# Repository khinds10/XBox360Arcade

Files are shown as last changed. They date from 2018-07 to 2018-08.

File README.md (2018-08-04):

# XBox360 Arcade - using a computer monitor speaker parts and 2 fightstick game pads, make an exciting arcade for your own home

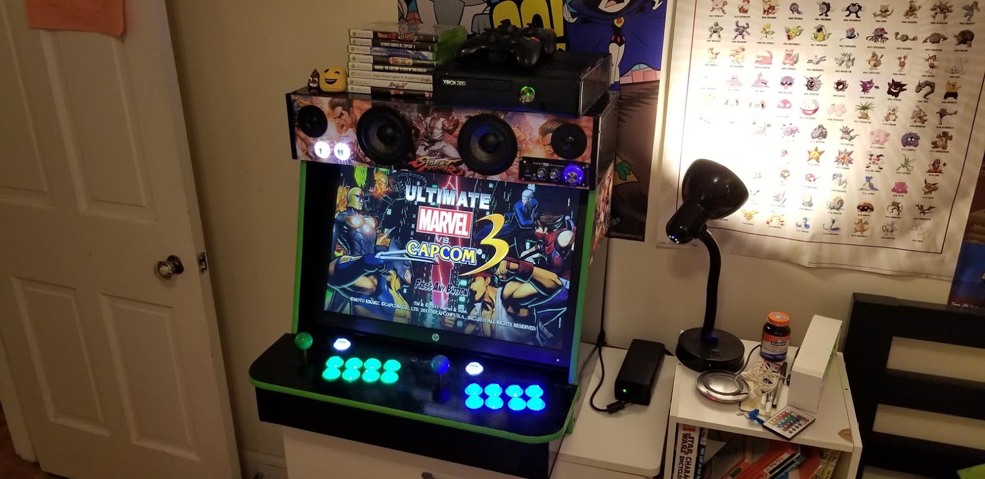
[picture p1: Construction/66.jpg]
Complete


## Supplied needed

### Construction Materials

#### Black Gloss Paint

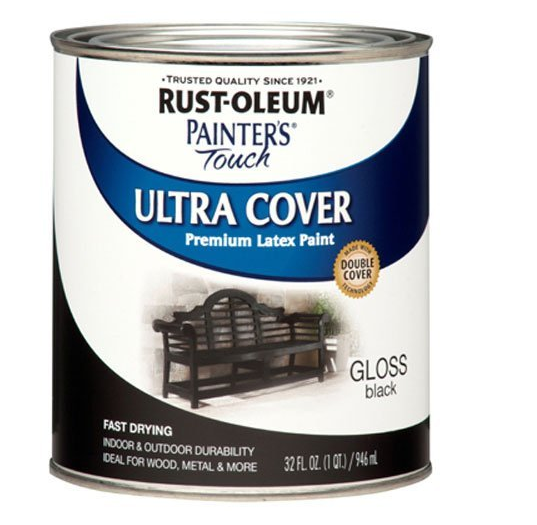
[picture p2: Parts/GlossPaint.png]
Black Gloss Paint


#### 1 inch Hole Saw

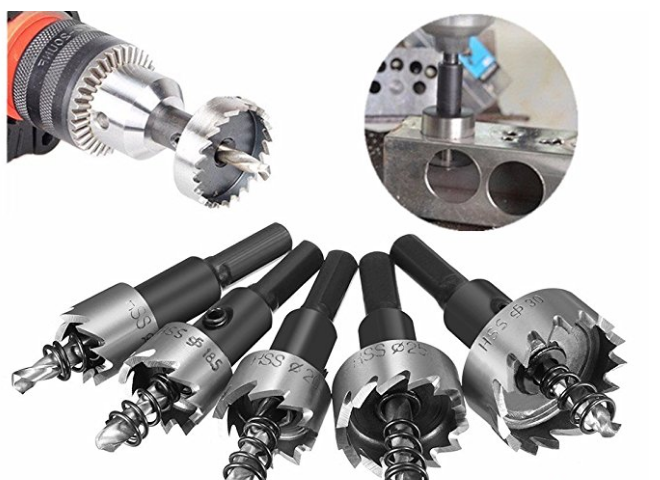
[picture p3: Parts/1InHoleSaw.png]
1 inch Hole Saw


#### Clear Gloss Coat

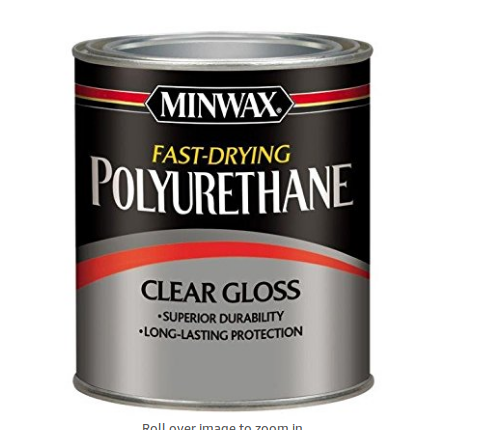
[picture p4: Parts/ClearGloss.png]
Clear Gloss Coat


#### 1x4 Wood Planks

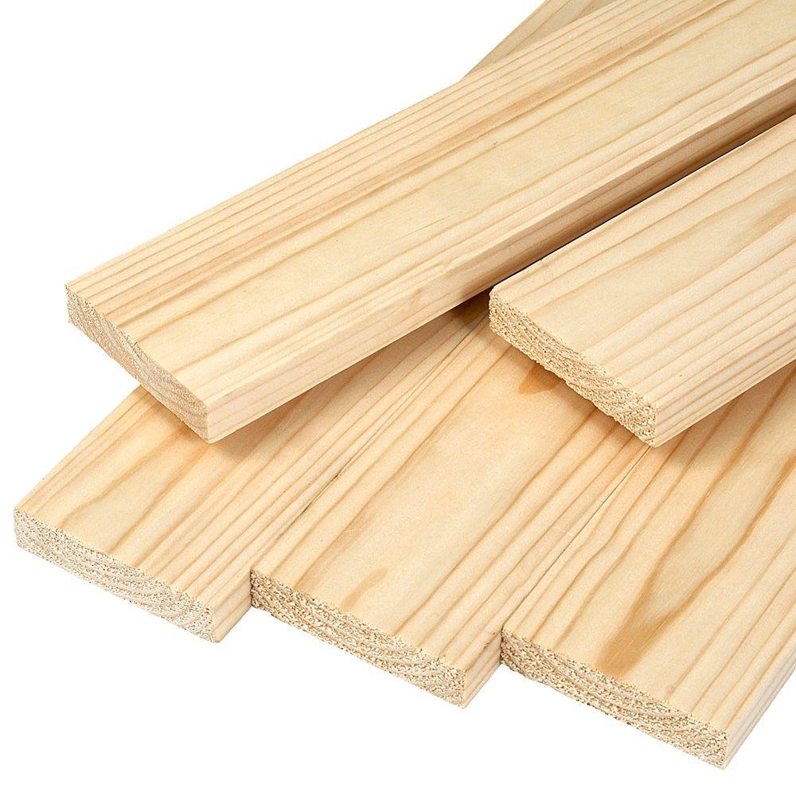
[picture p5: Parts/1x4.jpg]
1x4 Wood


#### Particle Board

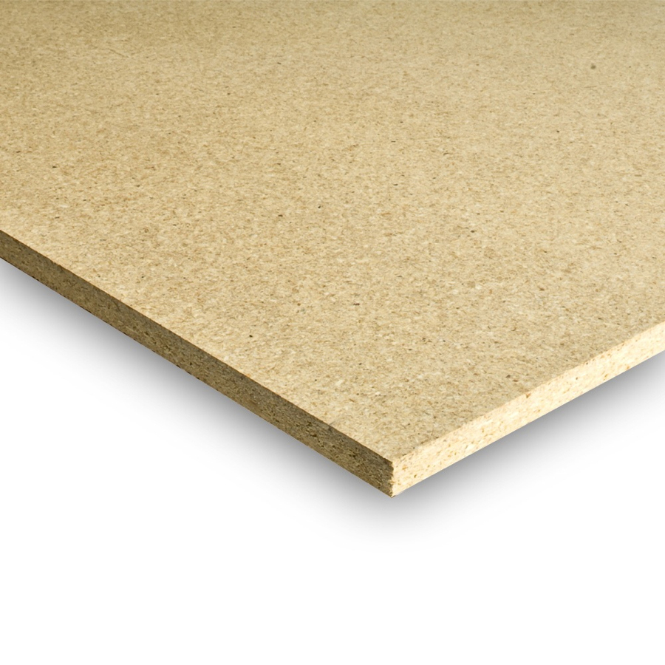
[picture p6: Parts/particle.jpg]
Particle Board


### Electronics

#### 24 inch Monitor

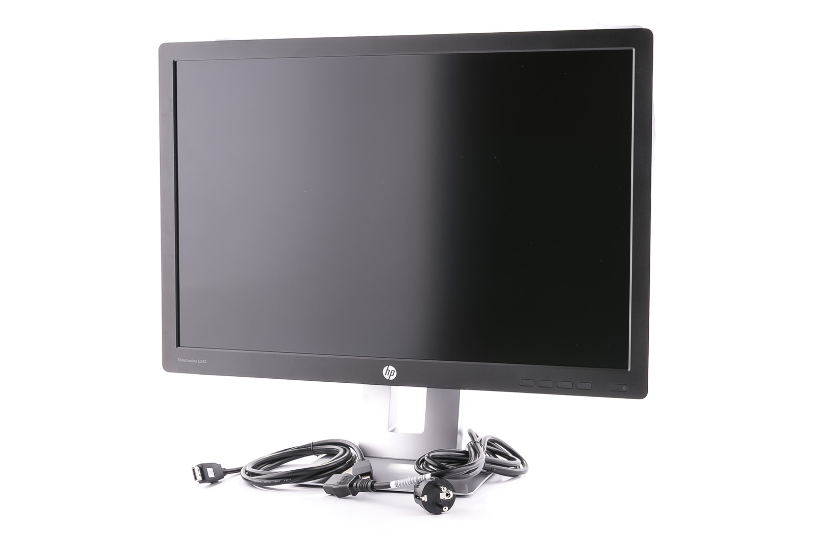
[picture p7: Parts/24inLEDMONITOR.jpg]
24 inch Monitor


#### Mini 12v Amplifier

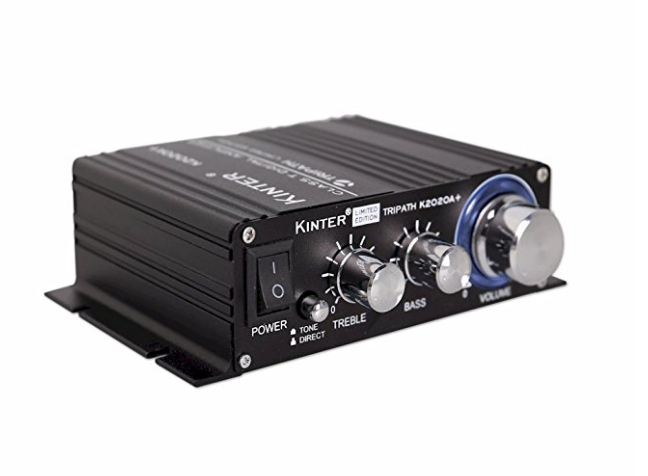
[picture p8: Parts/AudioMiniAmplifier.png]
Mini 12v Amplifier


#### XBox 360

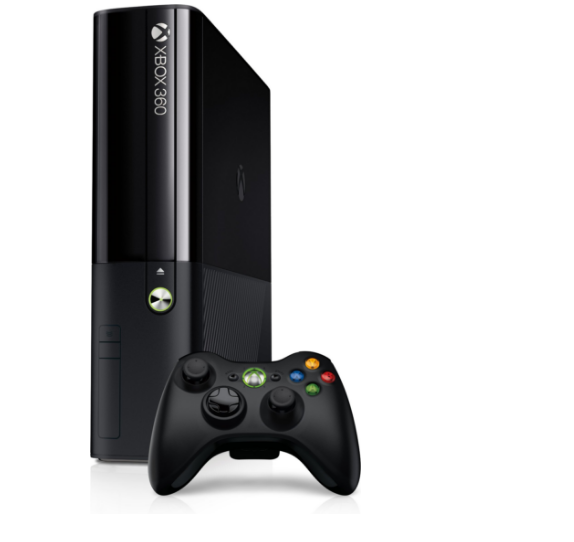
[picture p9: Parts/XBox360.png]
XBox 360


#### Fightstick (x2)

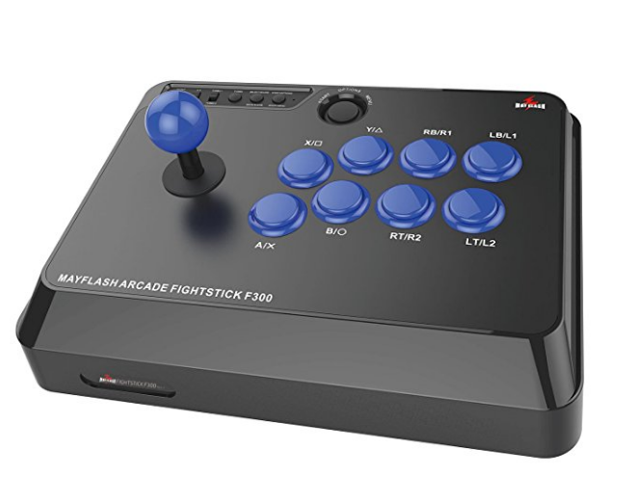
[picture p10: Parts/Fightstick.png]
Fightstick


#### XBox360 Controller (x2)

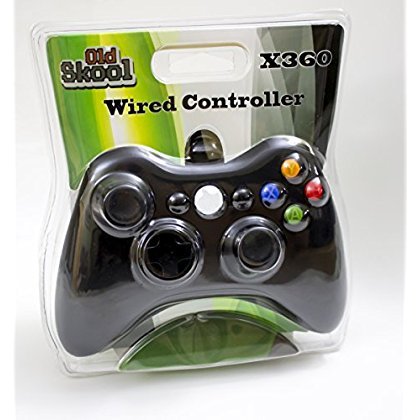
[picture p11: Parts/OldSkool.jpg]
XBox360 Controller (x2)


#### Power Strip

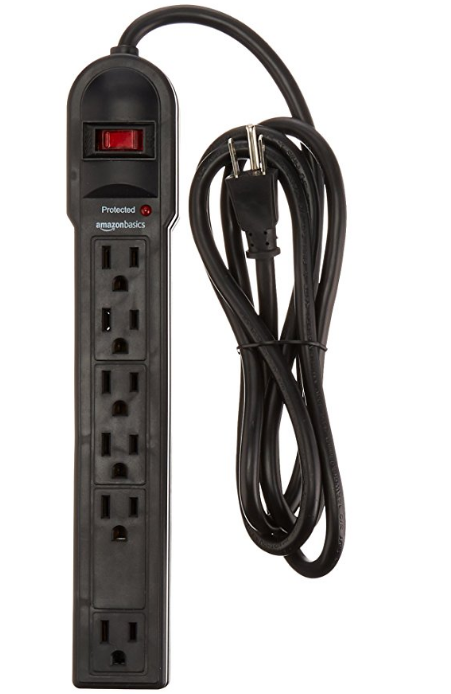
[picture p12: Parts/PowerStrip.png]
Power Strip


#### RCA Cables

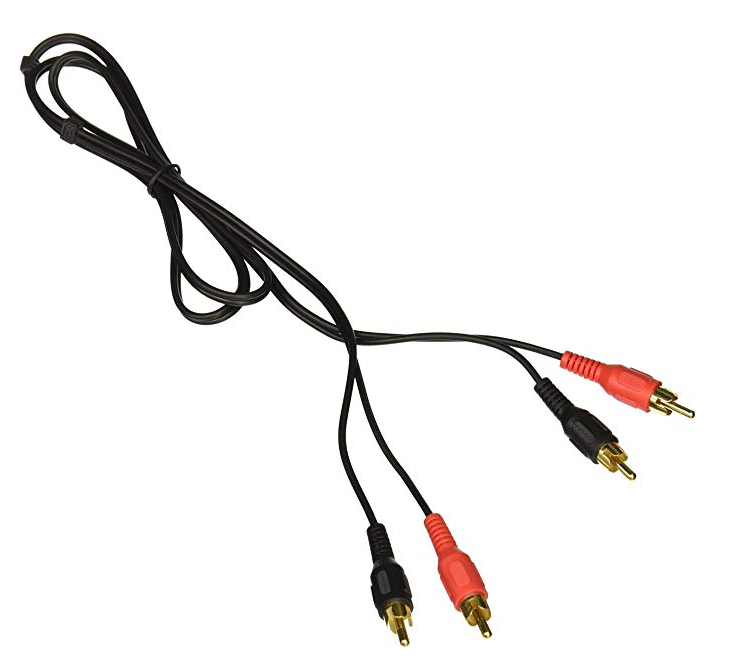
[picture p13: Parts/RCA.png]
RCA Cables


#### Small Speakers

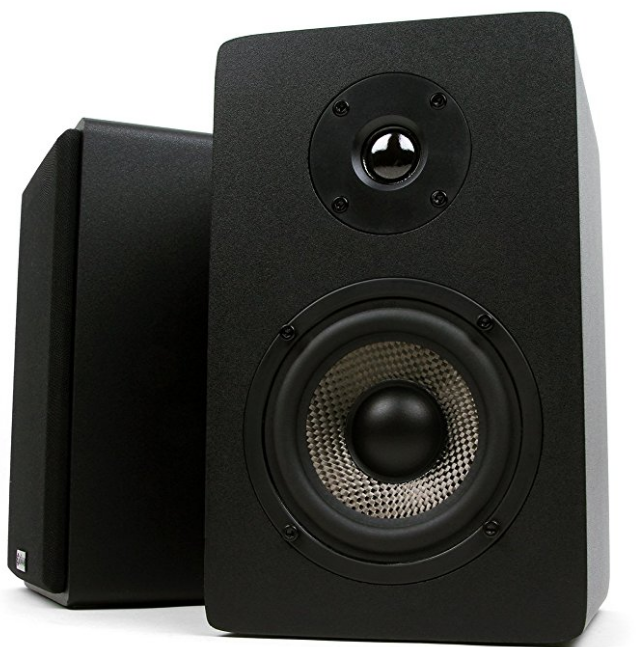
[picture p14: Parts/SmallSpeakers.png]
Small Speakers


#### HDMI Audio Extractor

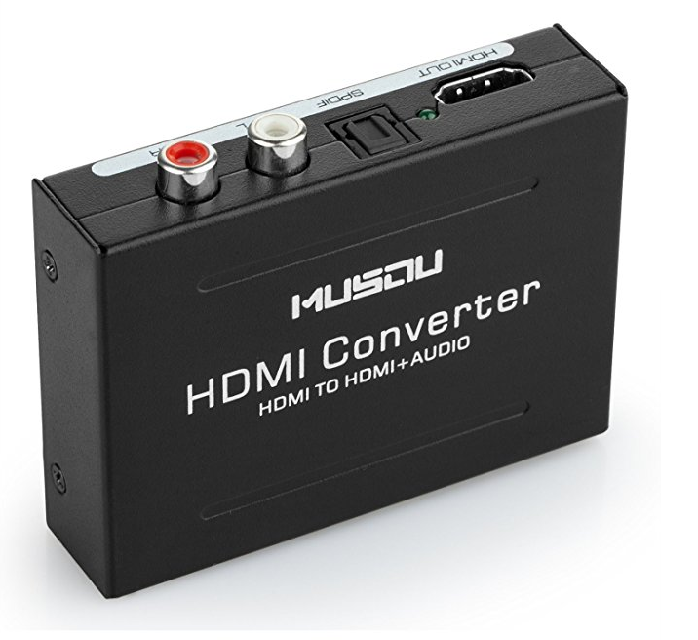
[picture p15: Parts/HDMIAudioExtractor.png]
HDMI Audio Extractor


#### Illuminated Buttons

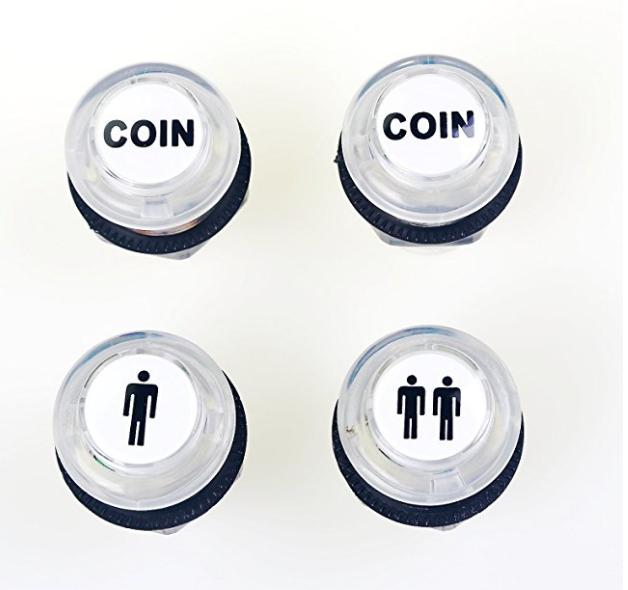
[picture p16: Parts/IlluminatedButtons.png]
Illuminated Buttons


#### Illuminated Buttons Kit

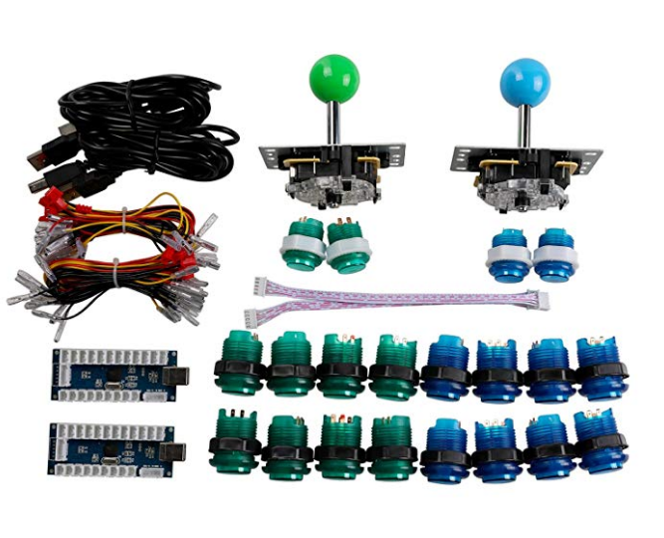
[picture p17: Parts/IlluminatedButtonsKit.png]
Illuminated Buttons Kit


#### Green TMolding

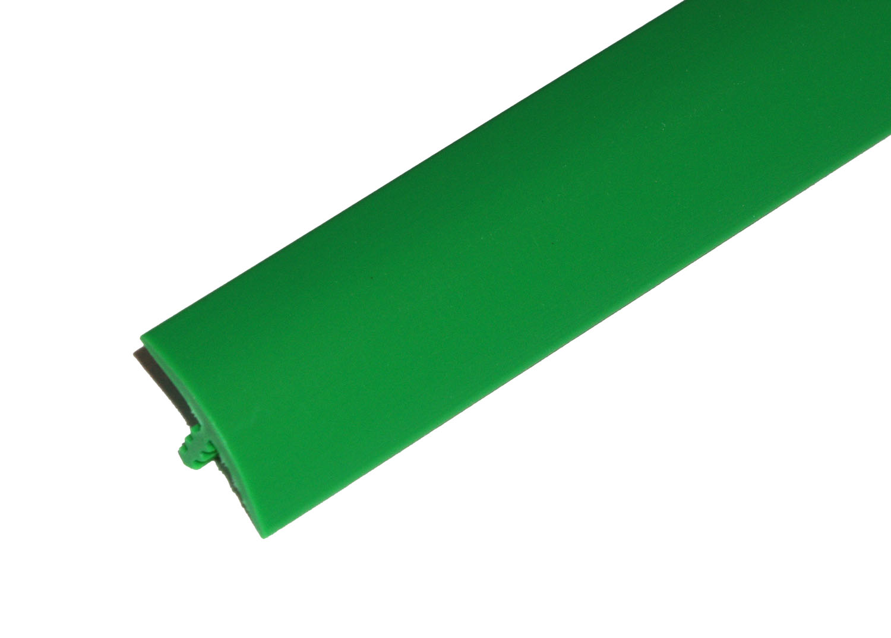
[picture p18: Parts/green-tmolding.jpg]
Green TMolding


### Exterior Decals

#### Decals

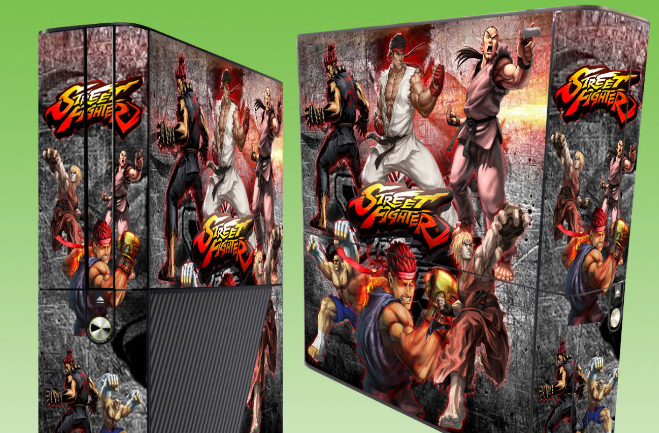
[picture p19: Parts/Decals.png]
Decals


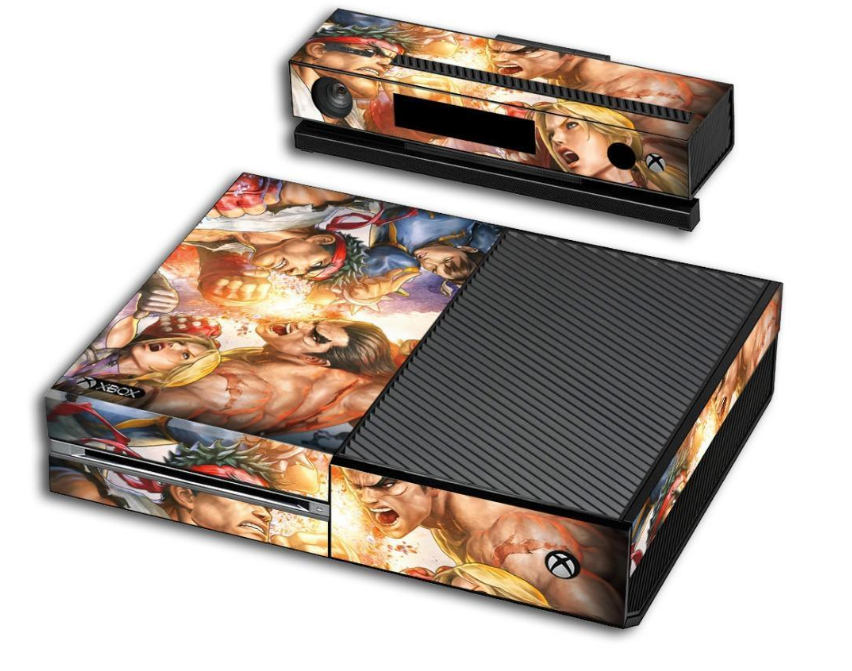
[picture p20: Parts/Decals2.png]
Decals


#### Embossed Branding Stickers

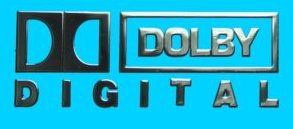
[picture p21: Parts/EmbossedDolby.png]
Dolby Sticker


XBox Sticker

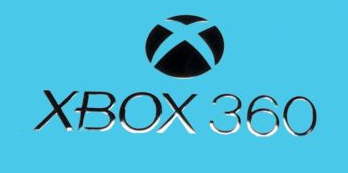
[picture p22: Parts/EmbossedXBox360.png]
XBox Sticker


## Building the Arcade

Because the Fightstick joysticks need an actual XBox360 controller plugged in to work and the "home" button has to be physically pressed on the joystick before the fightstick connects correctly, the following is needed to get the "home" or "player 1 / player 2" buttons to work on the arcade.

Take 2 XBox360 controllers and disassemble them.  Where the buttons would normally "press" (the circular metal contact connection), use a light sandpaper to expose the metal.

Soldered a "home" button connection directly to the contacts of where the home button would normally press if it was still put together.  This lets the joystick button "press" home as if it were a rubber button inside the original controller.

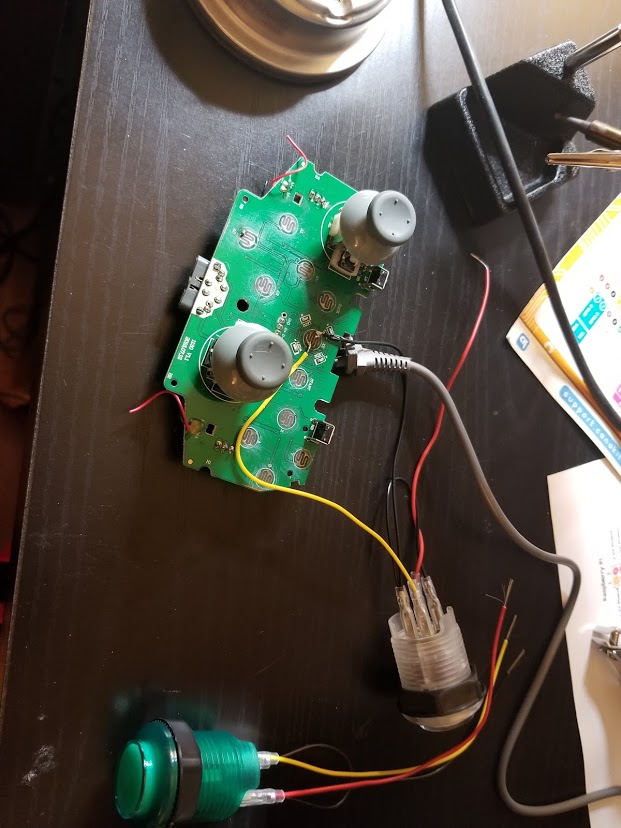
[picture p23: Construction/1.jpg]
Install Home Button


##### Build a basic Frame from the 1x4 planks to hold the monitor in place in the shape of an arcade cabinet

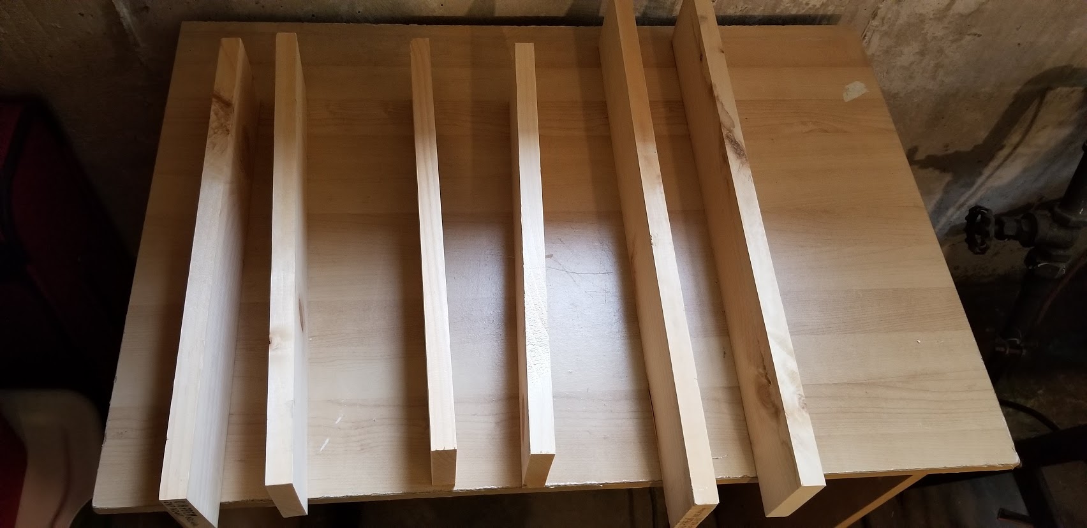
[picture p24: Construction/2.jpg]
Gather Wood

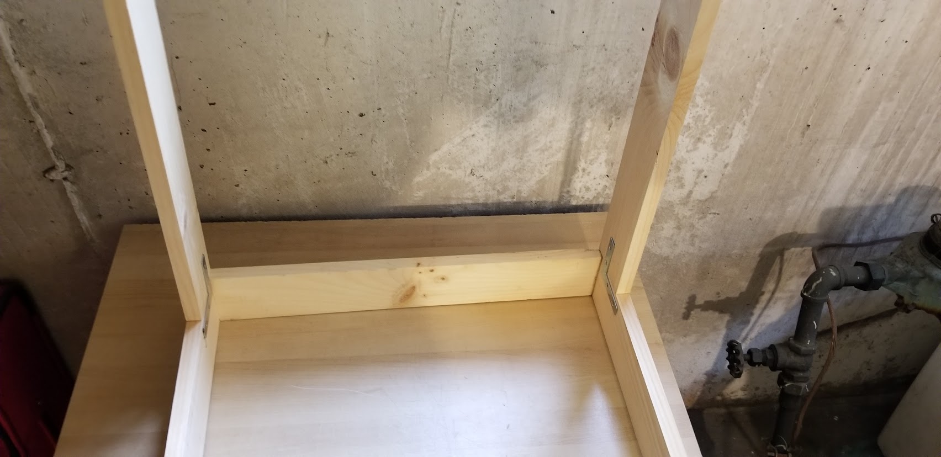
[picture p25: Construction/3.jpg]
Build Frame cont... Build Frame

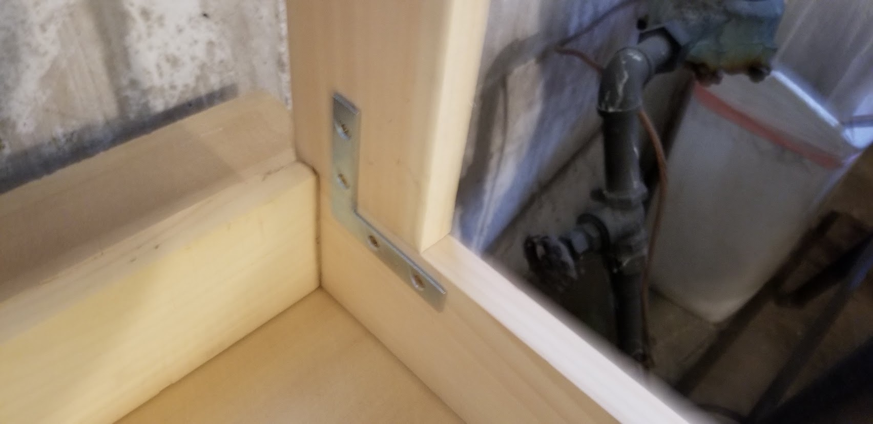
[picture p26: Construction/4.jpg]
Build Frame cont... Build Frame cont.

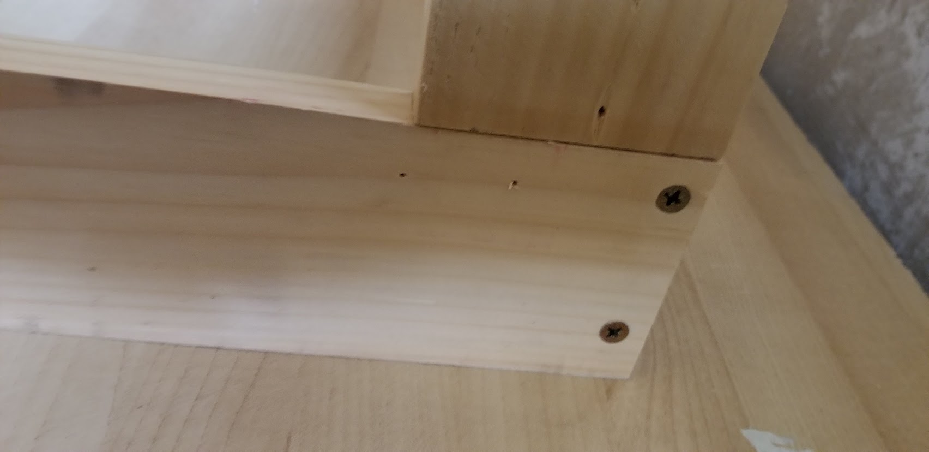
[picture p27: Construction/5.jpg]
Build Frame cont...


##### Make sure the monitor fits correctly across the build

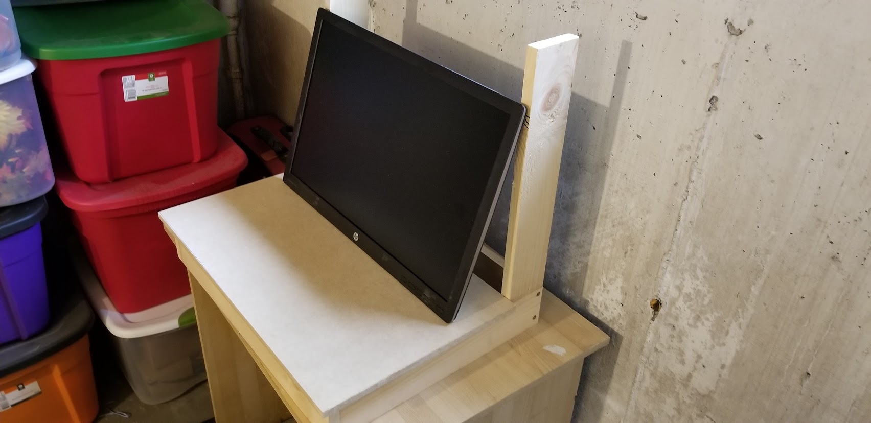
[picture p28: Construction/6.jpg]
Measure Monitor to fit

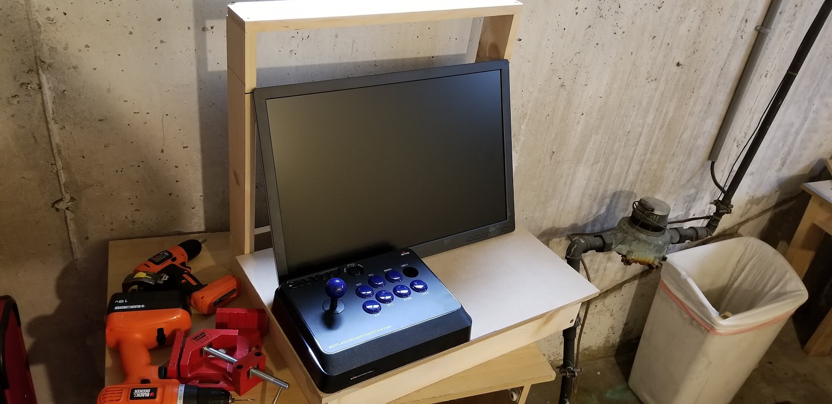
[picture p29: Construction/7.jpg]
Measure Monitor to fit cont...


##### Using the table saw, don't cut all the way through, but leave a slit in the wood where the bottom edge of the monitor would go, this will allow to place a thin piece of balsa wood to fit along it to keep the monitor from sliding out forward

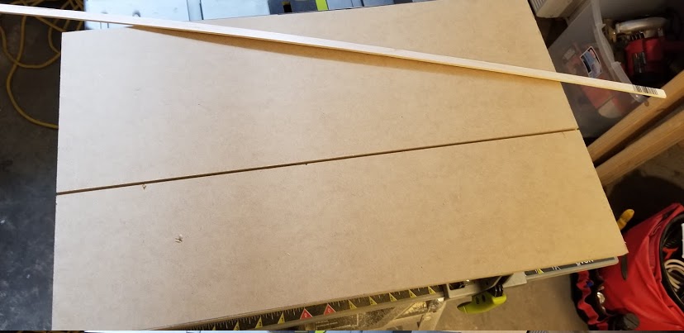
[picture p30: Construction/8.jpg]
Recess to hold monitor

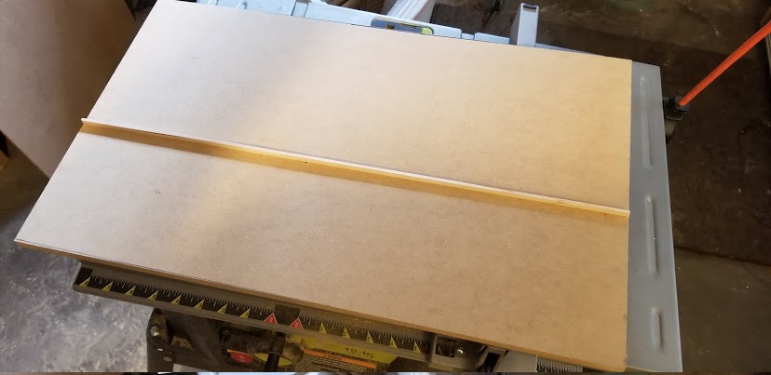
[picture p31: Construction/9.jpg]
Recess to hold monitor cont...


##### Using the fightstick button holes as a guide, drill using the 1" hole cutter the holes for where the buttons will go

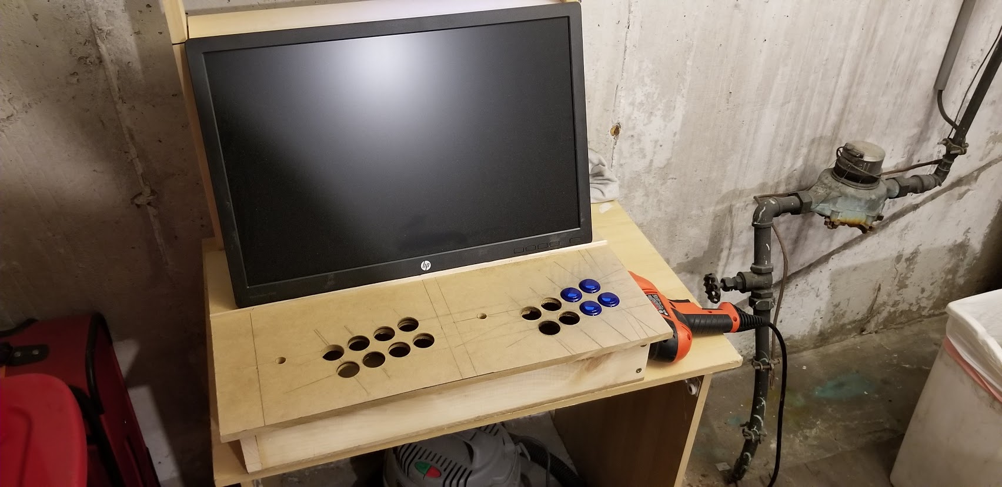
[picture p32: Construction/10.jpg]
Drill Button Holes

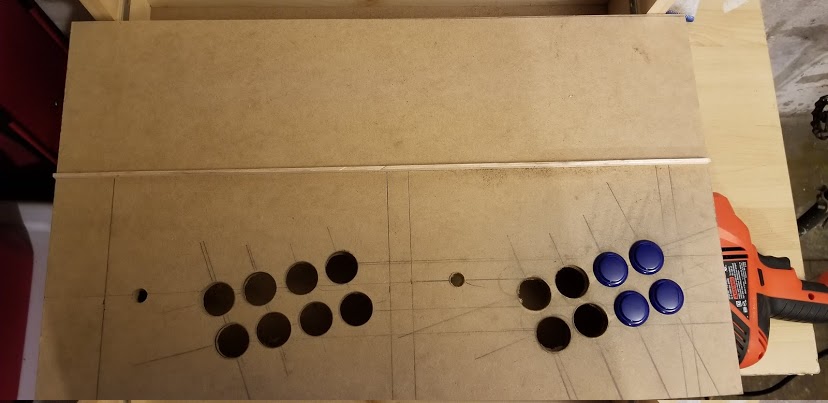
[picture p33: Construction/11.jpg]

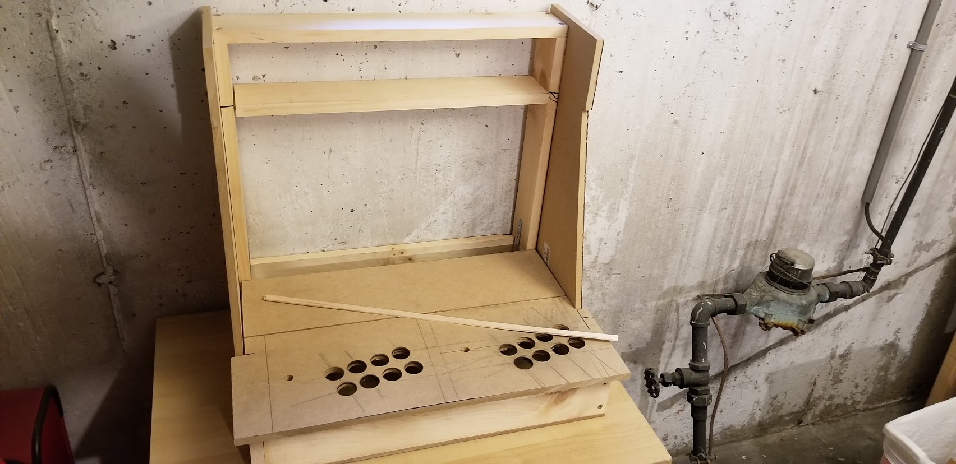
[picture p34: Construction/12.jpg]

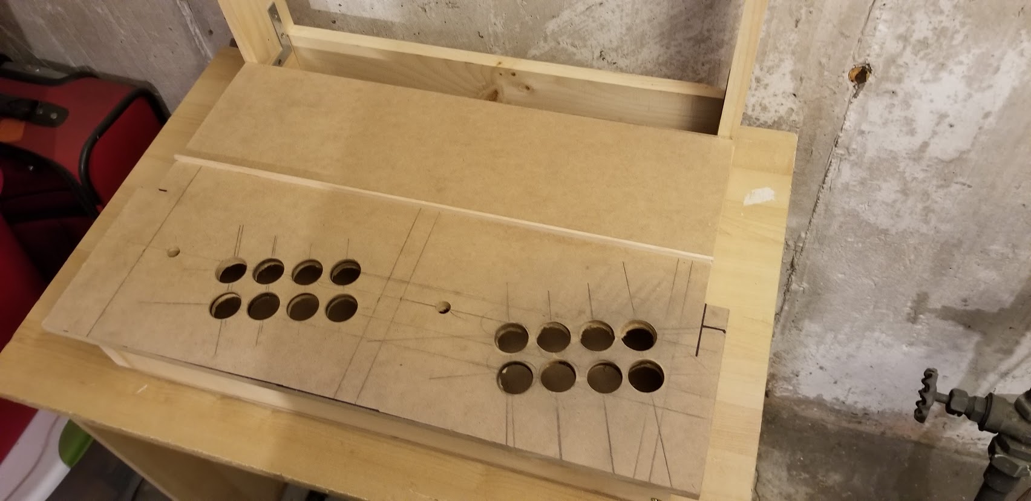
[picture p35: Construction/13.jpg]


##### With the particle board, cut the side panels with a triangular slant, however leaving the top in a square shape to contain the "top bar" where the amp / speakers will go

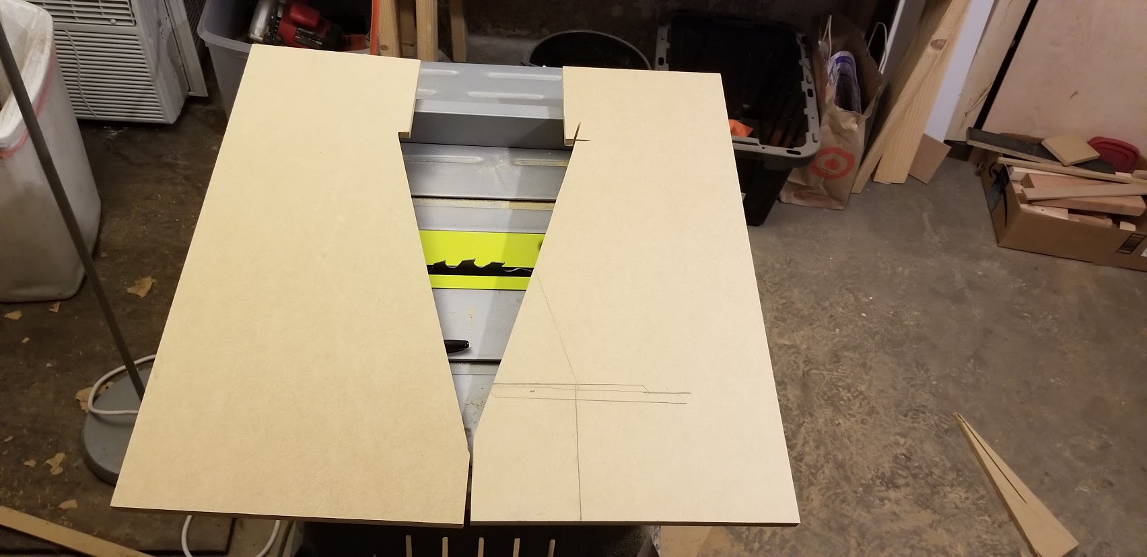
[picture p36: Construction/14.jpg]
Cut side panels from Particle Board

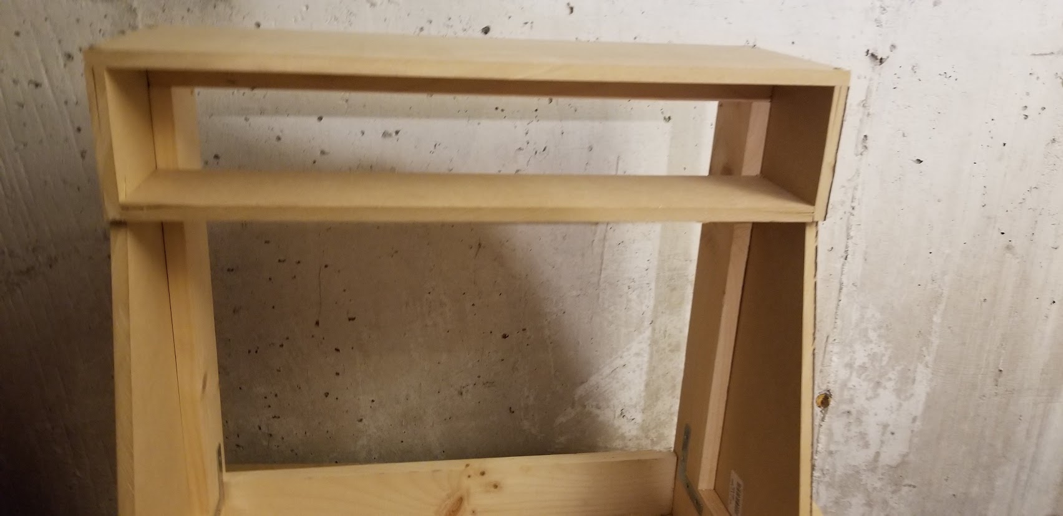
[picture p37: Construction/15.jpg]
Assemble top from 1x4 planks

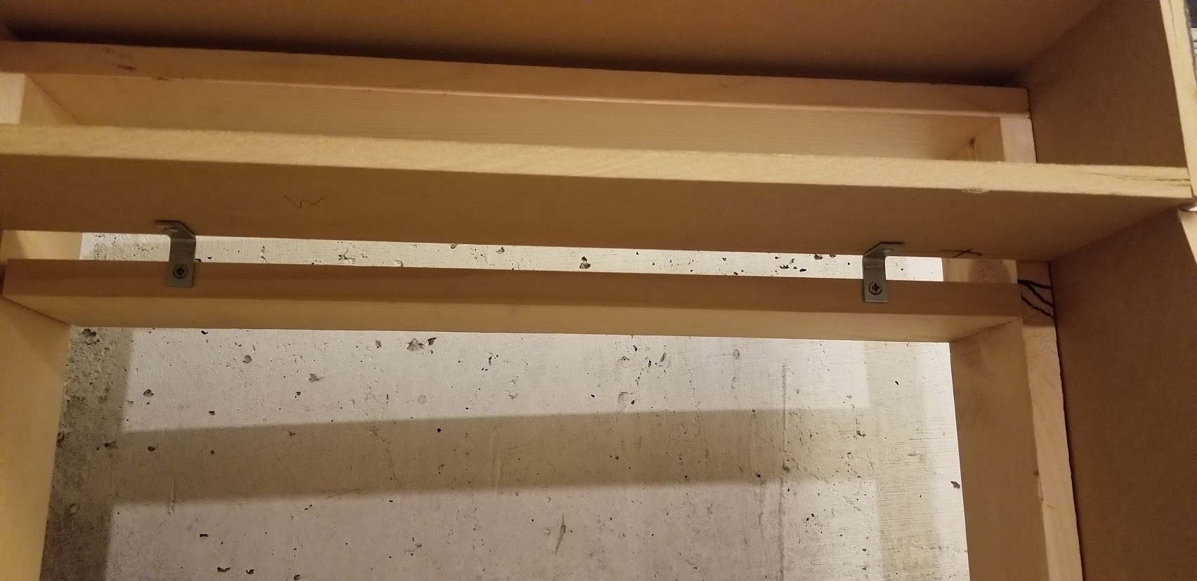
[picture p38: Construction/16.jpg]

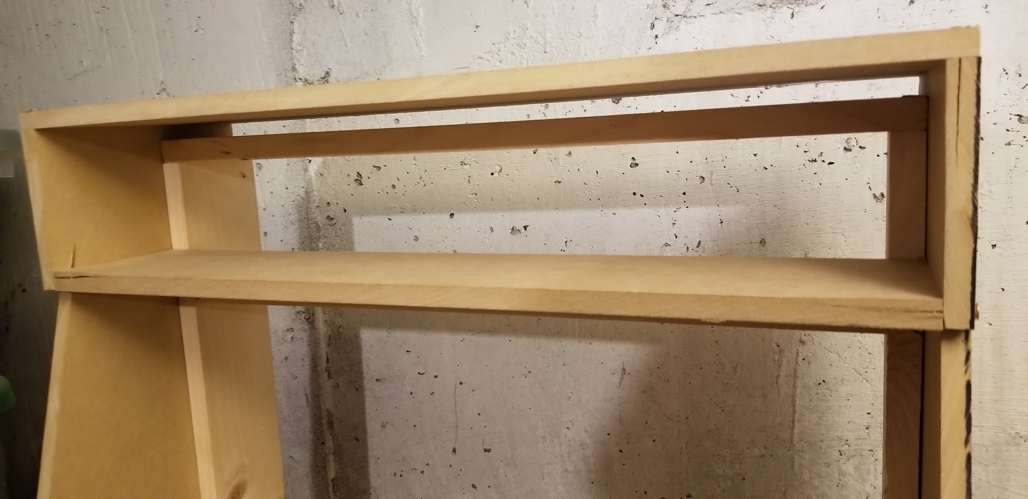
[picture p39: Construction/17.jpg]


##### Place the monitor in the build

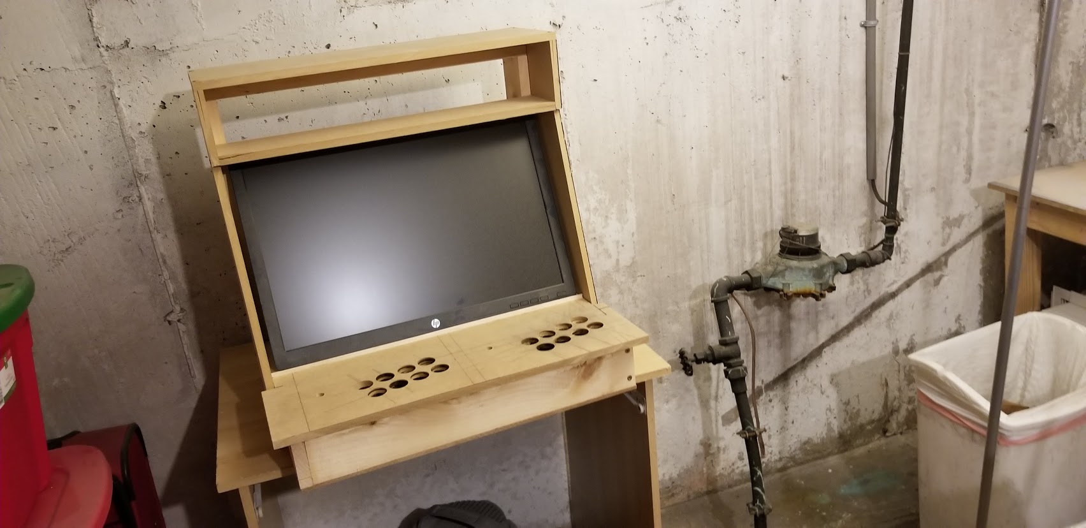
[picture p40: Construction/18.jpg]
Install Monitor

Make sure monitor fits
Make sure monitor fits cont...

##### Cut the rounded corners in the button container using a jigsaw and the small paint can as a guide to make it rounded off

Cut rounded corners
Cut rounded corners cont...
Cut rounded corners cont...

##### Get the amp and speakers together

Gather Amp and Speakers

#### Wiring the Arcade

Wiring Diagram

##### Prepare all the illuminated buttons for mounting in the cabinet.  Make sure all the wires are color coded for ease of construction, illumination lights as black and red.  Bound all the wires together so that the entire set of buttons receives power for illumination.

Prepare Illuminated Buttons for mounting

##### Take the back off the fightstick and observe the connections, we'll have to duplicate this inside our cabinet ourselves when we wire it together.

Observe Internals of the Fightstick
Observe Internals of the Fightstick cont...

##### Note the circuit boards inside specify conveniently which connectors go to the A/X/Y/B buttons and so on for our guide when wiring the cabinet.

Observe Internals of the Fightstick cont...

Wire Buttons under panel cont...

##### Connecting the buttons to a USB 5v power source (with 2 amp or higher rating) make sure they all illuminate correctly

Test Button Illumination
Test Button Illumination cont...
Test Button Illumination cont...

##### Using a small jigsaw cut holes for the 2 tweeters / woofers and small amp and make sure the mount correctly.

Mount Speakers and Amplifier
Mount Speakers and Amplifier cont...

##### Gather all the decals together and cut the 2 largest decals to make them appear on each side of the cabinet.

Gather Decals
Place Decals along the side
Place Decals along the side cont...

##### Mount the internal components and power source for final assembly.

Mount internal Components

##### Tape over the home button controller buttons to make sure that the wires stay put.

Make sure home button contacts are secure
Mount XBox360 Internal Controllers
Mount XBox360 Internal Controllers cont...

##### Cut a hole in the back for the wall power to enter and for the 2 controller USB cables / HDMI cable to extrude from to connect to your XBox360 console.

Wire the Power in the back

##### Place the decals squarely on the top bar where the speakers and amp are mounted.  Flip it over and cut with a razer blade the holes correctly.

Apply Decals to top Bar
Apply Decals to top Bar cont...
Cut Speaker and Amp through Decals

#### Make sure the top bar has the wiring it needs.  1) Power for the small amp.  2) Sound output coming from the HDMI audio extractor.  3) 5v power for the buttons (black and red wires) 4) Button leads (green and yellow wires)

Wire Top Bar
Attach Top Bar
Attach Top Bar cont...

##### Attaching the Green TMolding along the edges for a proper arcade cabinet look - I've used simple glue to glue the TMold to the edges of the arcade (cutting off the T part on the bottom)  If you do have a nice router you could cut the slots in the wood to have the TMolding fit correctly.

Install Green TMolding

##### Final Look

Finished! XXX

### Final Assembly

##### Mount the amplifier in the top bar using the 3DPrint/ folder "AmpSurround-Final.stl" model file to create a nice looking Amplifier black frame

Mount Amplifier with 3D Printed Surround Surround
Finished! XXX

### Plugin your XBox and Cabinet and you're ready to go!

Finished!

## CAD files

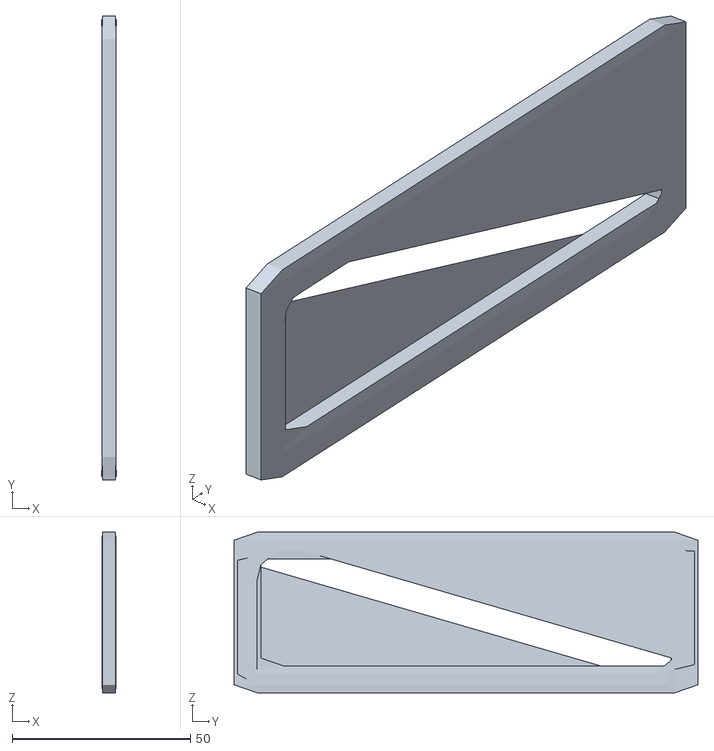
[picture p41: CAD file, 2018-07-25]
3DPrint/AmpSurround-Final.stl
4.00 x 130.0 x 45.0

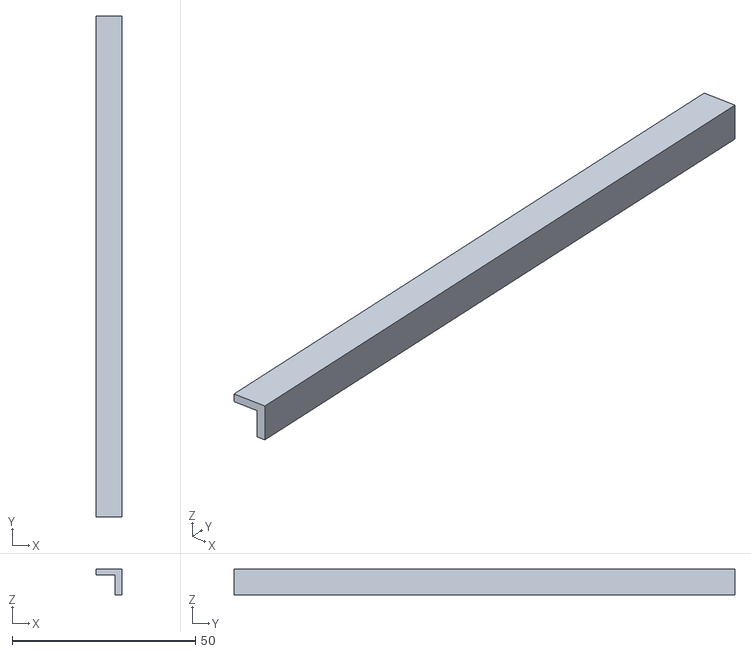
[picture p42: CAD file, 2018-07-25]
3DPrint/borders.stl
7.00 x 136.5 x 7.00

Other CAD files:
3DPrint/AmpSurround-Final.blend
3DPrint/AmpSurround.blend
3DPrint/borders.blend

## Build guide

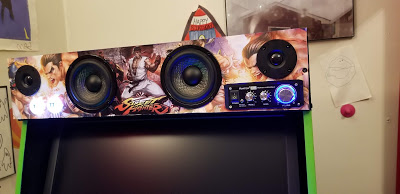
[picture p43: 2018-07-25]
Construction/65.jpg

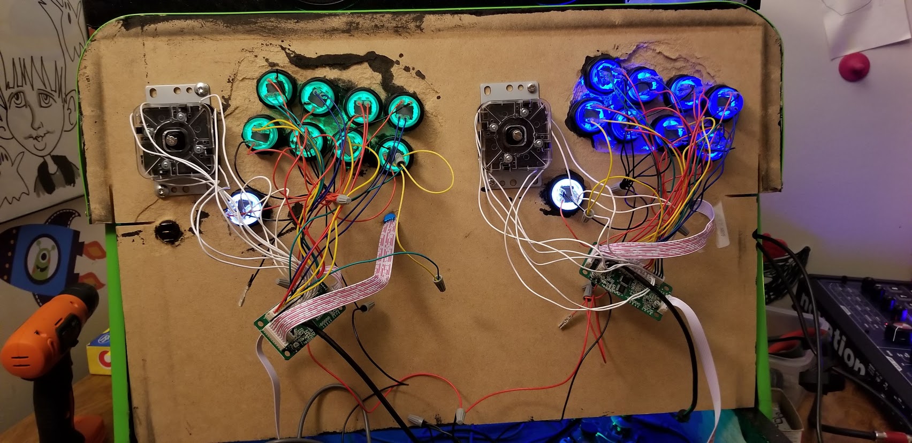
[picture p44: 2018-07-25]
Construction/43.jpg
